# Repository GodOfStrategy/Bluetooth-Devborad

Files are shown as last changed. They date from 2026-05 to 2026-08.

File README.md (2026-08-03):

# Custom Bluetooth Devboard 
This is a cutom bluetooth devboard made by me for IoT and short range communication and automation. 
This board uses a nRF 52840 QIAA-F-R7 along with a RP2040 for processing, wired together with SPI.
It also uses 2 crystals 12MHz and 32 MHz for thr Rp 2040 and the nRF 52840 respectively.
A TLV75533PDBV (LDO) as my Voltage regulator.
2 USB-C receptacles for programming both chips with firmware.
SMD resistors.
SMD capacitors.
Here is my schematic:


Here is my PCB:


Here is the 3D Imge of my PCB:


Here is my BoM of PCB components:
[BLE_DEV_001_bom.csv](https://github.com/user-attachments/files/30661502/BLE_DEV_001_bom.csv)

Please find all production and firmware files in my repo.

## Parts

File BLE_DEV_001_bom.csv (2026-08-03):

Designator | Footprint | Quantity | Value | LCSC Part #
AE1 | PinSocket_1x01_P2.54mm_Vertical | 1 | Ant
C1, C2, C3, C4, C5 | 0402 | 5 | 100 nF
C10, C9 | 0402 | 2 | 12pF
C11, C26, C28, C30 | 0402 | 4 | 1uF
C12 | 0402 | 1 | 4.7uF
C13, C14 | 0402 | 2 | 4.7 uF
C17 | 0402 | 1 | 100nF
C18 | 0402 | 1 | 0.8 pF
C19 | 0402 | 1 | 0.5 pF
C20, C21, C22, C23, C24, C25, C27, C7 | 0402 | 8 | 0.1uF
C29 | 0402 | 1 | 0.1uF (C27-C28)
C31 | 1206 | 1 | 200uF
C32, C33 | 0402 | 2 | 33pF
C6 | 0402 | 1 | 0.1uF (C6-25)
C8 | 0402 | 1 | 100pF
D1, D2 | 0402 | 2 | LED
J1, J2 | USB_C_Receptacle_HCTL_HC-TYPE-C-16P-01A | 2 | USB_C_Receptacle_USB2.0_16P
J3 | PinHeader_1x21_P2.54mm_Vertical | 1 | Conn_01x21_Pin(RP)
J4 | PinHeader_1x21_P2.54mm_Vertical | 1 | Conn_01x21_Pin (RP)
J5, J6 | PinHeader_1x15_P2.54mm_Vertical | 2 | Conn_01x15_Pin
L1 | 0402 | 1 | 4.7nH
R1, R2, R3, R4 | 0402 | 4 | 5.1K
R10, R14 | 0402 | 2 | 10K
R11, R9 | 0402 | 2 | 1K
R12, R13 | 0402 | 2 | 330
R5, R6, R7, R8 | 0402 | 4 | 27
RESET(NRF), SW1 | SW_SPST_PTS647_Sx38 | 2 | SW_Push
U1 | SOIC-8_5.3x5.3mm_P1.27mm | 1 | W25Q128JVS
U2 | QFN-56-1EP_7x7mm_P0.4mm_EP3.2x3.2mm | 1 | RP2040
U3 | SOT-23-5 | 1 | TLV75533PDBV
U4 | QIAA-F-R7 | 1 | ~
Y1 | FA128 | 1 | FA-128
Y2 | Crystal_SMD_3225-4Pin_3.2x2.5mm | 1 | 12 MHz

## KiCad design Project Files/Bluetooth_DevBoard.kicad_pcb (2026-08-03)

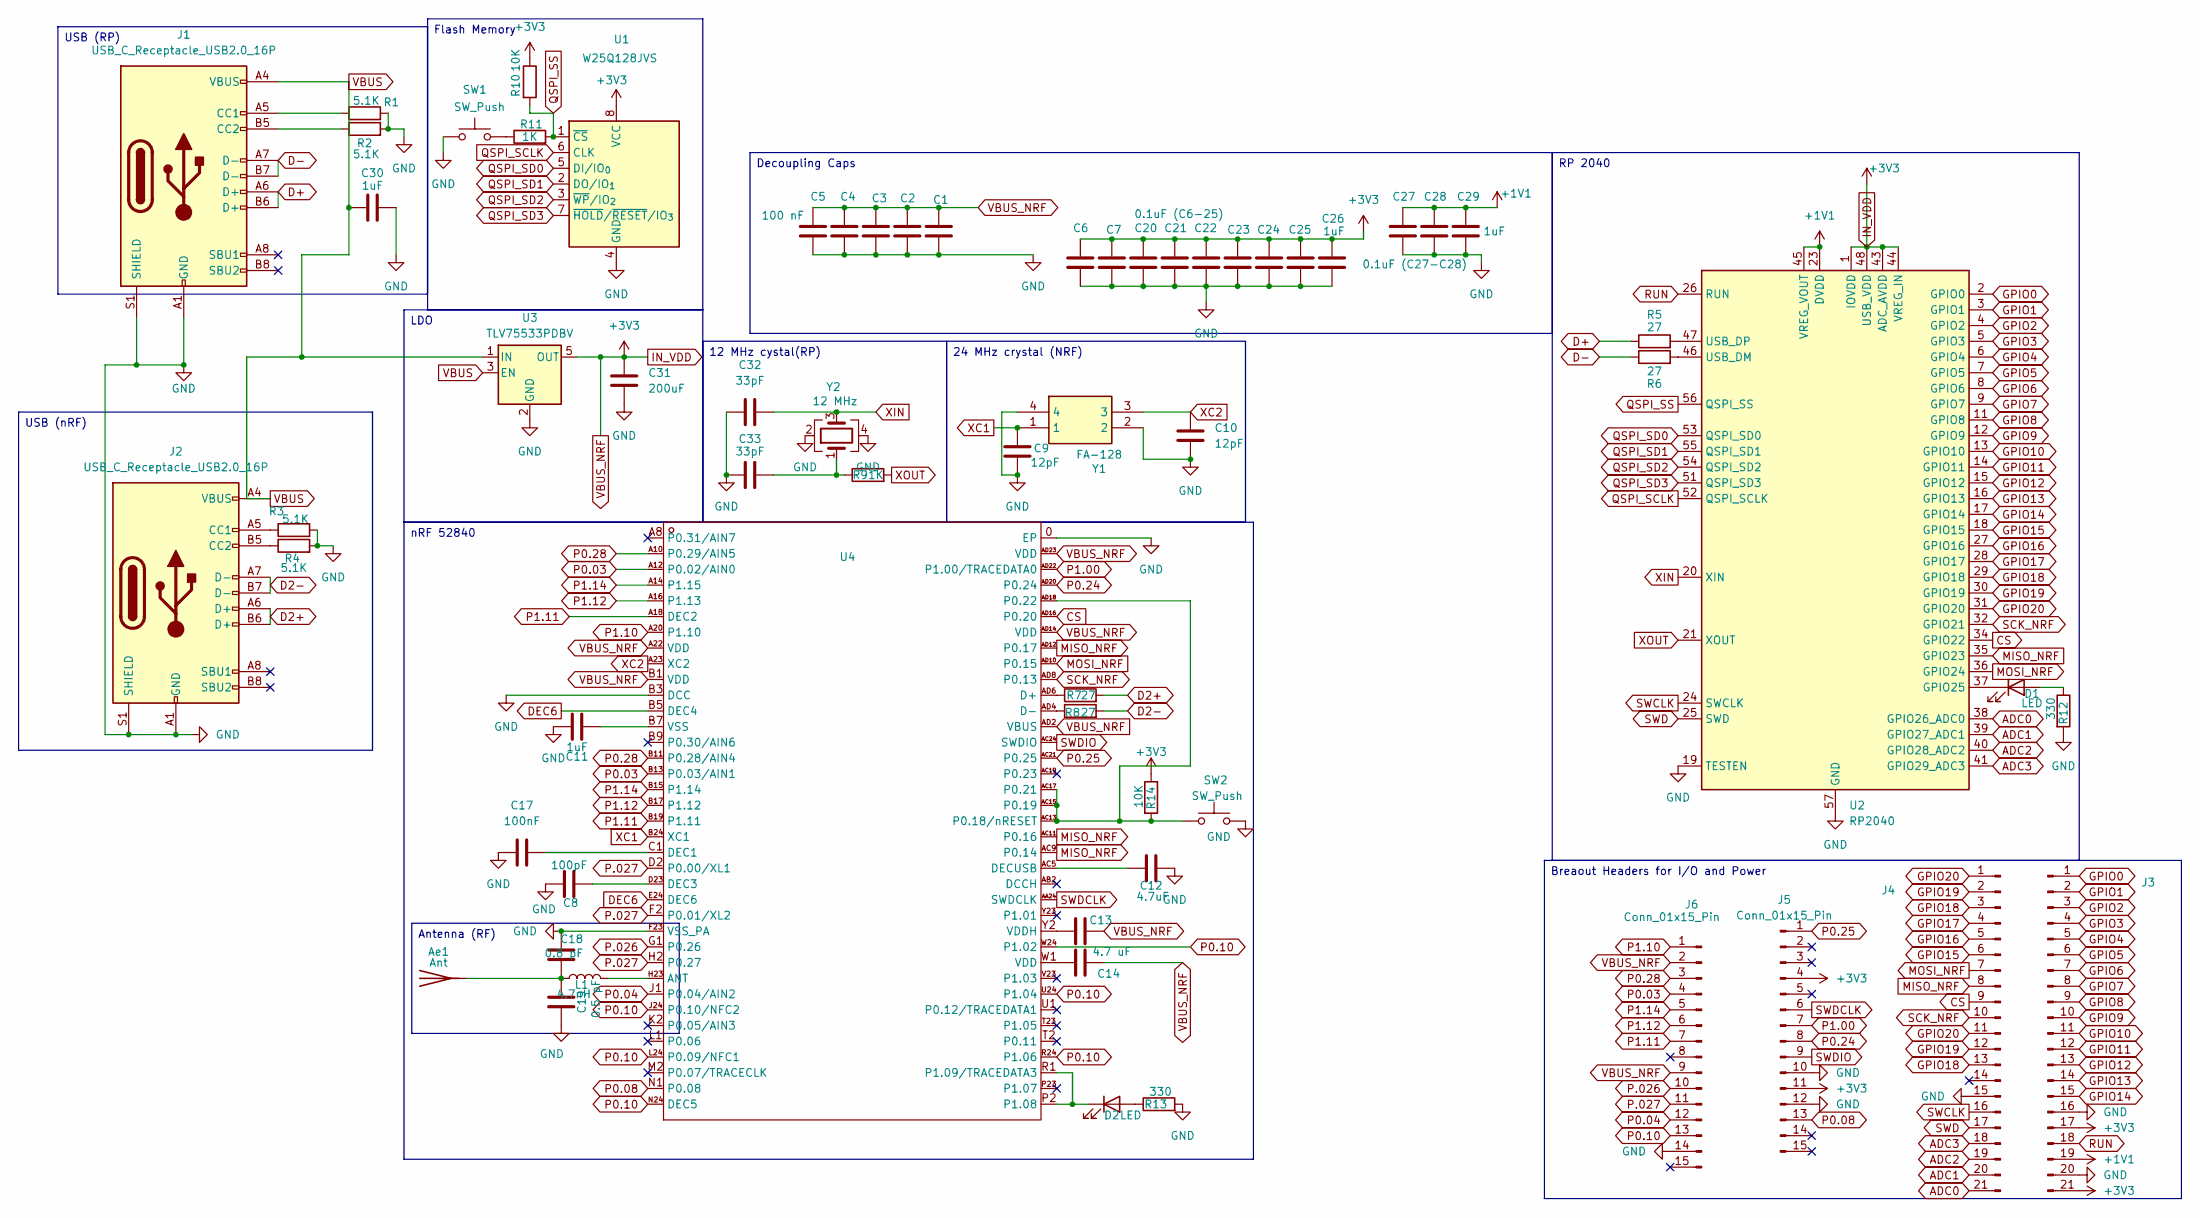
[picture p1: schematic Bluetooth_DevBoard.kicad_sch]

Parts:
Ae1: Ant; PinSocket_1x01_P2.54mm_Vertical
C1, C2, C3, C4, C5: 100 nF; C_0402_1005Metric
C6: 0.1uF (C6-25); C_0402_1005Metric
C7, C20, C21, C22, C23, C24, C25, C27: 0.1uF; C_0402_1005Metric
C8: 100pF; C_0402_1005Metric
C9, C10: 12pF; C_0402_1005Metric
C11, C26, C28, C30: 1uF; C_0402_1005Metric
C12: 4.7uF; C_0402_1005Metric
C13, C14: 4.7 uF; C_0402_1005Metric
C17: 100nF; C_0402_1005Metric
C18: 0.8 pF; C_0402_1005Metric
C19: 0.5 pF; C_0402_1005Metric
C29: 0.1uF (C27-C28); C_0402_1005Metric
C31: 200uF; C_1206_3216Metric
C32, C33: 33pF; C_0402_1005Metric
D1, D2: LED; D_0402_1005Metric
J1, J2: USB_C_Receptacle_USB2.0_16P; USB_C_Receptacle_HCTL_HC-TYPE-C-16P-01A
J3: Conn_01x21_Pin(RP); PinHeader_1x21_P2.54mm_Vertical
J4: Conn_01x21_Pin (RP); PinHeader_1x21_P2.54mm_Vertical
J5, J6: Conn_01x15_Pin; PinHeader_1x15_P2.54mm_Vertical
L1: 4.7nH; L_0402_1005Metric
R1, R2, R3, R4: 5.1K; R_0402_1005Metric
R5, R6, R7, R8: 27; R_0402_1005Metric
R9, R11: 1K; R_0402_1005Metric
R10, R14: 10K; R_0402_1005Metric
R12, R13: 330; R_0402_1005Metric
SW1, SW2: SW_Push; SW_SPST_PTS647_Sx38
U1: W25Q128JVS; SOIC-8_5.3x5.3mm_P1.27mm
U2: RP2040; QFN-56-1EP_7x7mm_P0.4mm_EP3.2x3.2mm
U3: TLV75533PDBV; SOT-23-5
U4: QIAA-F-R7; Manufacturer Part NRF52840-QIAA-F-R7; LCSC Part Name NRF52840-QIAA-F-R7
Y1: FA-128; FA128; Manufacturer_Part_Number Q22FA12800025 FA-128 32 MHZ 8.0PF
Y2: 12 MHz; Crystal_SMD_3225-4Pin_3.2x2.5mm

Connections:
+1V1: C27.1, C28.1, C29.1, J3.19, U2.23 (DVDD), U2.45 (VREG_VOUT), U2.50 (DVDD)
ADC0: J4.21, U2.38 (GPIO26_ADC0)
ADC1: J4.20, U2.39 (GPIO27_ADC1)
ADC2: J4.19, U2.40 (GPIO28_ADC2)
ADC3: J4.18, U2.41 (GPIO29_ADC3)
CS: J4.9, U2.34 (GPIO22), U4.AD16 (P0.20)
D2+: J2.A6 (D+), J2.B6 (D+), R7.2
D2-: J2.A7 (D-), J2.B7 (D-), R8.2
D+: J1.A6 (D+), J1.B6 (D+), R5.1
D-: J1.A7 (D-), J1.B7 (D-), R6.1
DEC6: U4.B5 (DEC4), U4.E24 (DEC6)
GND: C1.2, C2.2, C3.2, C4.2, C5.2, C6.2, C7.2, C8.2, C9.1, C10.2, C11.1, C12.2, C17.1, C18.2, C19.1, C20.2, C21.2, C22.2, C23.2, C24.2, C25.2, C26.2, C27.2, C28.2, C29.2, C30.2, C31.1, C32.1, C33.1, J1.A1 (GND), J1.A12 (GND), J1.B1 (GND), J1.B12 (GND), J1.S1 (SHIELD), J2.A1 (GND), J2.A12 (GND), J2.B1 (GND), J2.B12 (GND), J2.S1 (SHIELD), J3.16, J3.20, J4.15, J5.10, J5.12, J6.14, R1.2, R2.2, R3.2, R4.2, R12.2, R13.2, SW1.1, SW2.2, U1.4 (GND), U2.19 (TESTEN), U2.57 (GND), U3.2 (GND), U4.0 (EP), U4.B3 (DCC), U4.F23 (VSS_PA), Y1.2, Y1.4, Y2.2, Y2.4; also elsewhere on the board
GPIO0: J3.1, U2.2 (GPIO0)
GPIO1: J3.2, U2.3 (GPIO1)
GPIO2: J3.3, U2.4 (GPIO2)
GPIO3: J3.4, U2.5 (GPIO3)
GPIO4: J3.5, U2.6 (GPIO4)
GPIO5: J3.6, U2.7 (GPIO5)
GPIO6: J3.7, U2.8 (GPIO6)
GPIO7: J3.8, U2.9 (GPIO7)
GPIO8: J3.9, U2.11 (GPIO8)
GPIO9: J3.10, U2.12 (GPIO9)
GPIO10: J3.11, U2.13 (GPIO10)
GPIO11: J3.12, U2.14 (GPIO11)
GPIO12: J3.13, U2.15 (GPIO12)
GPIO13: J3.14, U2.16 (GPIO13)
GPIO14: J3.15, U2.17 (GPIO14)
GPIO15: J4.6, U2.18 (GPIO15)
GPIO16: J4.5, U2.27 (GPIO16)
GPIO17: J4.4, U2.28 (GPIO17)
GPIO18: J4.3, J4.13, U2.29 (GPIO18)
GPIO19: J4.2, J4.12, U2.30 (GPIO19)
GPIO20: J4.1, J4.11, U2.31 (GPIO20)
IN_VDD: C1.1, C2.1, C3.1, C4.1, C5.1, C6.1, C7.1, C13.2, C14.1, C20.1, C21.1, C22.1, C23.1, C24.1, C25.1, C26.1, C31.2, J3.17, J3.21, J5.4, J5.11, J6.2, J6.9, R10.1, R14.1, U1.8 (VCC), U2.1 (IOVDD), U2.10 (IOVDD), U2.22 (IOVDD), U2.33 (IOVDD), U2.42 (IOVDD), U2.43 (ADC_AVDD), U2.44 (VREG_IN), U2.48 (USB_VDD), U2.49 (IOVDD), U3.5 (OUT), U4.A22 (VDD), U4.AD2 (VBUS), U4.AD14 (VDD), U4.AD23 (VDD), U4.B1 (VDD)
MISO_NRF: J4.8, U2.35 (GPIO23), U4.AC9 (P0.14), U4.AC11 (P0.16), U4.AD12 (P0.17)
MOSI_NRF: J4.7, U2.36 (GPIO24), U4.AD10 (P0.15)
unnamed: Ae1.1 (A), C18.1, C19.2, L1.1
unnamed: C14.2, U4.W1 (VDD)
unnamed: C33.2, R9.1, Y2.1
unnamed: D1.2 (A), R12.1
unnamed: D1.1 (K), U2.37 (GPIO25)
unnamed: D2.2 (A), R13.1
unnamed: D2.1 (K), U4.P2 (P1.08), U4.R1 (P1.09/TRACEDATA3)
unnamed: J1.A5 (CC1), R1.1
unnamed: J1.B5 (CC2), R2.1
unnamed: J2.A5 (CC1), R3.1
unnamed: J2.B5 (CC2), R4.1
unnamed: R11.1, SW1.2
unnamed: R6.2, U2.46 (USB_DM)
unnamed: R5.2, U2.47 (USB_DP)
unnamed: L1.2, U4.H23 (ANT)
unnamed: R7.1, U4.AD6 (D+)
unnamed: R8.1, U4.AD4 (D-)
unnamed: C17.2, U4.C1 (DEC1)
unnamed: C8.1, U4.D23 (DEC3)
unnamed: C12.1, U4.AC5 (DECUSB)
unnamed 56: R14.2, SW2.1, U4.AC13 (P0.18/nRESET), U4.AC15 (P0.19), U4.AC17 (P0.21), U4.AD18 (P0.22); also elsewhere on the board
unnamed: C13.1, U4.Y2 (VDDH)
unnamed: C11.2, U4.B7 (VSS)
P0.03: J6.4, U4.A12 (P0.02/AIN0), U4.B13 (P0.03/AIN1)
P0.04: J6.12, U4.J1 (P0.04/AIN2)
P0.08: J5.13, U4.N1 (P0.08)
P0.10: J6.13, U4.J24 (P0.10/NFC2), U4.L24 (P0.09/NFC1), U4.N24 (DEC5), U4.R24 (P1.06), U4.U24 (P1.04), U4.W24 (P1.02)
P0.24: J5.8, U4.AD20 (P0.24)
P0.25: J5.1, U4.AC21 (P0.25)
P0.28: J6.3, U4.A10 (P0.29/AIN5), U4.B11 (P0.28/AIN4)
P1.00: J5.7, U4.AD22 (P1.00/TRACEDATA0)
P1.10: J6.1, U4.A20 (P1.10)
P1.11: J6.7, U4.A18 (DEC2), U4.B19 (P1.11)
P1.12: J6.6, U4.A16 (P1.13), U4.B17 (P1.12)
P1.14: J6.5, U4.A14 (P1.15), U4.B15 (P1.14)
P.026: J6.10, U4.G1 (P0.26)
P.027: J6.11, U4.D2 (P0.00/XL1), U4.F2 (P0.01/XL2), U4.H2 (P0.27)
QSPI_SCLK: U1.6 (CLK), U2.52 (QSPI_SCLK)
QSPI_SD0: U1.5 (DI/IO_{0}), U2.53 (QSPI_SD0)
QSPI_SD1: U1.2 (DO/IO_{1}), U2.55 (QSPI_SD1)
QSPI_SD2: U1.3 (~WP/IO_{2}), U2.54 (QSPI_SD2)
QSPI_SD3: U1.7 (~HOLD/~RESET/IO_{3}), U2.51 (QSPI_SD3)
QSPI_SS: R10.2, R11.2, U1.1 (~CS), U2.56 (QSPI_SS)
RUN: J3.18, U2.26 (RUN)
SCK_NRF: J4.10, U2.32 (GPIO21), U4.AD8 (P0.13)
SWCLK: J4.16, U2.24 (SWCLK)
SWD: J4.17, U2.25 (SWD)
SWDCLK: J5.6, U4.AA24 (SWDCLK)
SWDIO: J5.9, U4.AC24 (SWDIO)
VBUS: C30.1, J1.A4 (VBUS), J1.A9 (VBUS), J1.B4 (VBUS), J1.B9 (VBUS), J2.A4 (VBUS), J2.A9 (VBUS), J2.B4 (VBUS), J2.B9 (VBUS), U3.1 (IN), U3.3 (EN)
XC1: C9.2, U4.B24 (XC1), Y1.1
XC2: C10.1, U4.A23 (XC2), Y1.3
XIN: C32.2, U2.20 (XIN), Y2.3
XOUT: R9.2, U2.21 (XOUT)

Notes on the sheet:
Decoupling Caps
Flash Memory
USB (RP)
Antenna (RF)
USB (nRF)
12 MHz cystal(RP)
24 MHz crystal (NRF)
LDO
RP 2040
Breaout Headers for I/O and Power
nRF 52840

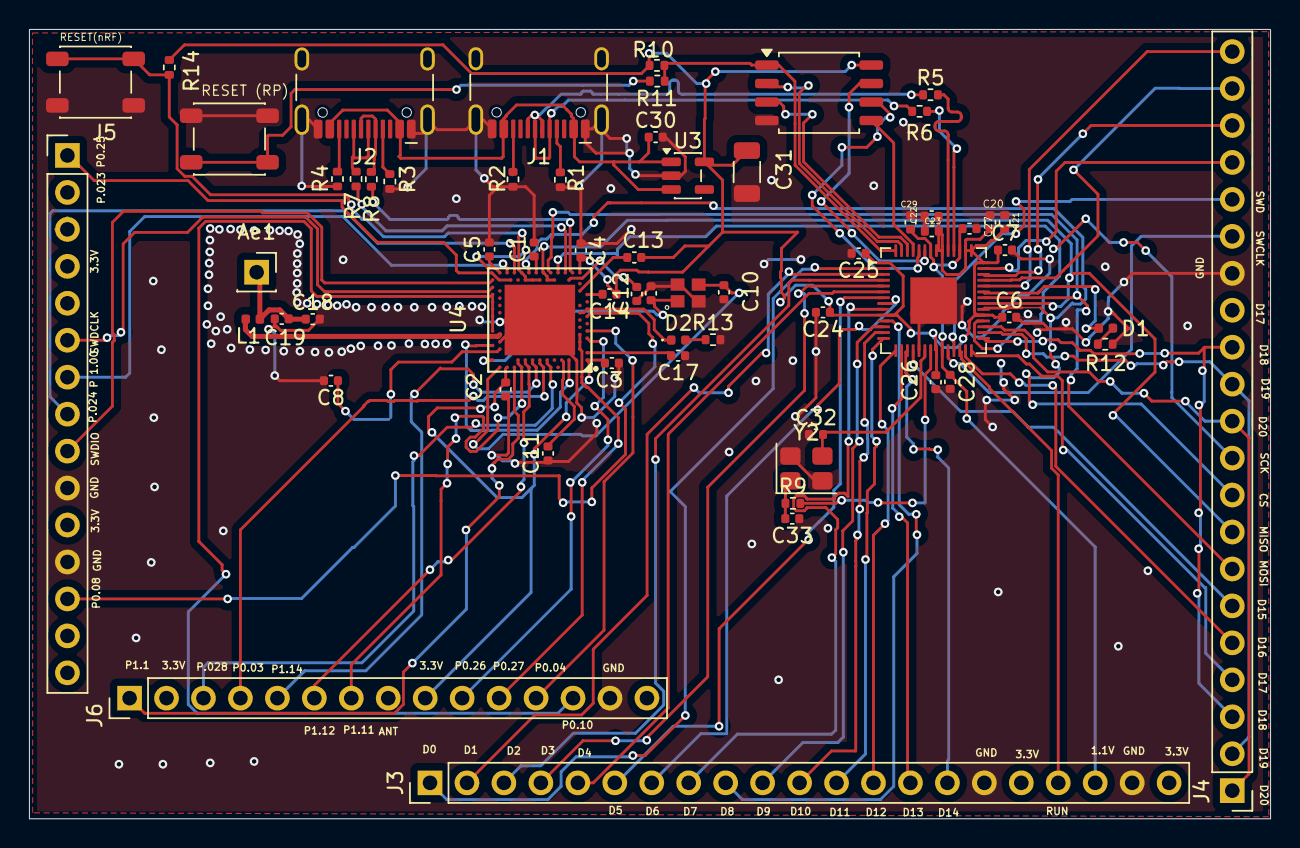
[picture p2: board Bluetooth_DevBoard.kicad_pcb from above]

Board: 4 copper layers, 85.3 x 54.2 mm, 63 parts (0 on the bottom side), 90 nets.

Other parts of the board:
RESET(nRF): SW_Push; SW_SPST_PTS647_Sx38

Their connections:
GND: RESET(nRF).2; also elsewhere on the board
unnamed 56: RESET(nRF).1; also elsewhere on the board

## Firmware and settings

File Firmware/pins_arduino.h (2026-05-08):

#pragma once

// Pin definitions taken from:
//    https://datasheets.raspberrypi.org/pico/pico-datasheet.pdf

// LEDs


// Serial
#define PIN_SERIAL1_TX (0u)
#define PIN_SERIAL1_RX (1u)

#define PIN_SERIAL2_TX (8u)
#define PIN_SERIAL2_RX (9u)

// SPI0 pins (required by common.h)
#define PIN_SPI0_SS    (22u)  // CS
#define PIN_SPI0_MOSI  (24u)  // MOSI_NRF
#define PIN_SPI0_MISO  (23u)  // MISO_NRF
#define PIN_SPI0_SCK   (21u)  // SCK_NRF




// Leave SPI1 as default (unused in your schematic)
#define PIN_SPI1_MISO  (12u)
#define PIN_SPI1_MOSI  (15u)
#define PIN_SPI1_SCK   (14u)
#define PIN_SPI1_SS    (13u)

// Wire
#define PIN_WIRE0_SDA  (4u)
#define PIN_WIRE0_SCL  (5u)

#define PIN_WIRE1_SDA  (26u)
#define PIN_WIRE1_SCL  (27u)

#define SERIAL_HOWMANY (3u)
#define SPI_HOWMANY    (2u)
#define WIRE_HOWMANY   (2u)

#include "../generic/common.h"
